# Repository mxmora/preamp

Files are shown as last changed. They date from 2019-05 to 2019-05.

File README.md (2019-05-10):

# preamp
Guitar buffer preamp

Added buffer input front end
Added more mounting holes

Version 1.1.4 only has the channel A clean section.
Version 1.1.4 has been built and tested and works with no error. Four minor errors were corrected and new boards were made.

Added Distortion Section
changed version to 1.2.0

This now has an A/B section A for clean and B for Lead Channel. 

Added LED for channel B indicator.

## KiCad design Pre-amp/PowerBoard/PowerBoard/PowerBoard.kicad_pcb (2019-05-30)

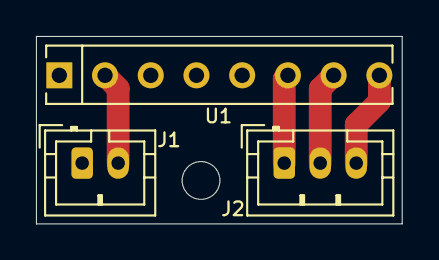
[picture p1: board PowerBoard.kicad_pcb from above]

Board: 2 copper layers, 20.3 x 10.4 mm, 4 parts (0 on the bottom side), 5 nets.

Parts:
H1: MountingHole; MountingHole_2.1mm
J1: Conn_01x02_Male; JST_PH_B2B-PH-K_1x02_P2.00mm_Vertical
J2: Conn_01x03_Male; JST_PH_B3B-PH-K_1x03_P2.00mm_Vertical
U1: DPAN02; SIP-8_19x3mm_P2.54mm

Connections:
+9V: J1.2, U1.2
+15V: J2.1, U1.6
-15V: J2.3, U1.8
GND: J1.1, U1.1
unnamed: J2.2, U1.7

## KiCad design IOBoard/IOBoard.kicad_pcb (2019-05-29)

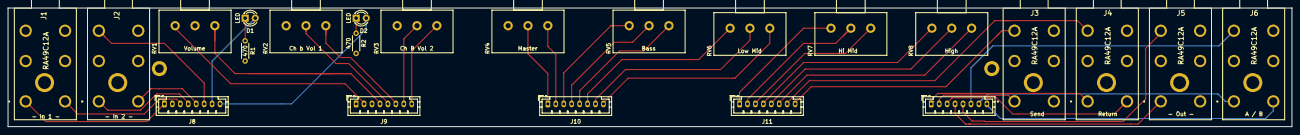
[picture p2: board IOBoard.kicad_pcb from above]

Board: 2 copper layers, 323.2 x 29.8 mm, 25 parts (0 on the bottom side), 40 nets.

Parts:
D1, D2: LED; LED_D3.0mm
H1, H2: MountingHole_Pad; MountingHole_2.2mm_M2_DIN965_Pad
J1, J2, J3, J4, J5, J6: RA49C12A; RA49C14B
J7, J8, J9, J10, J11: Conn_01x08_Male; JST_PH_B8B-PH-K_1x08_P2.00mm_Vertical
R1, R2: 470; R_Axial_DIN0204_L3.6mm_D1.6mm_P5.08mm_Horizontal
RV1: Volume; Potentiometer_Alps_RK163_Single_Horizontal
RV2: Ch b Vol 1; Potentiometer_Alps_RK163_Single_Horizontal
RV3: Ch B Vol 2; Potentiometer_Alps_RK163_Single_Horizontal
RV4: Master; Potentiometer_Alps_RK163_Single_Horizontal
RV5: Bass; Potentiometer_Alps_RK163_Single_Horizontal
RV6: Low Mid; Potentiometer_Alps_RK163_Single_Horizontal
RV7: Hi Mid; Potentiometer_Alps_RK163_Single_Horizontal
RV8: High; Potentiometer_Alps_RK163_Single_Horizontal

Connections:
GND: H1.1, H2.1, J1.5, J8.2, J9.3, R1.2, R2.2, RV1.2, RV2.3, RV3.3, RV4.3
unnamed: D1.1, R1.1
unnamed: D1.2, J8.7
unnamed: D2.1, R2.1
unnamed: D2.2, J8.8
unnamed: J1.1, J8.1
unnamed: J1.2, J8.3
unnamed: J2.1, J8.4
unnamed: J2.2, J8.5
unnamed: J2.5, J8.6
unnamed: J3.1, J7.2
unnamed: J4.1, J7.1
unnamed: J4.2, J7.3
unnamed: J5.1, J7.4
unnamed: J5.5, J7.5
unnamed: J6.1, J7.7
unnamed: J6.2, J7.8
unnamed: J6.5, J7.6
unnamed: J9.2, RV1.3
unnamed: J9.4, RV1.1
unnamed: J9.5, RV2.2
unnamed: J9.6, RV2.1
unnamed: J9.7, RV3.2
unnamed: J9.8, RV3.1
unnamed: J10.1, RV4.2
unnamed: J10.2, RV4.1
unnamed: J10.3, RV5.3
unnamed: J10.4, RV5.2
unnamed: J10.5, RV5.1
unnamed: J10.6, RV6.3
unnamed: J10.7, RV6.2
unnamed: J10.8, RV6.1
unnamed: J11.1, RV7.3
unnamed: J11.2, RV7.2
unnamed: J11.3, RV7.1
unnamed: J11.4, RV8.3
unnamed: J11.5, RV8.2
unnamed: J11.6, RV8.1
unnamed: J4.5, J11.7
unnamed: J3.5, J11.8

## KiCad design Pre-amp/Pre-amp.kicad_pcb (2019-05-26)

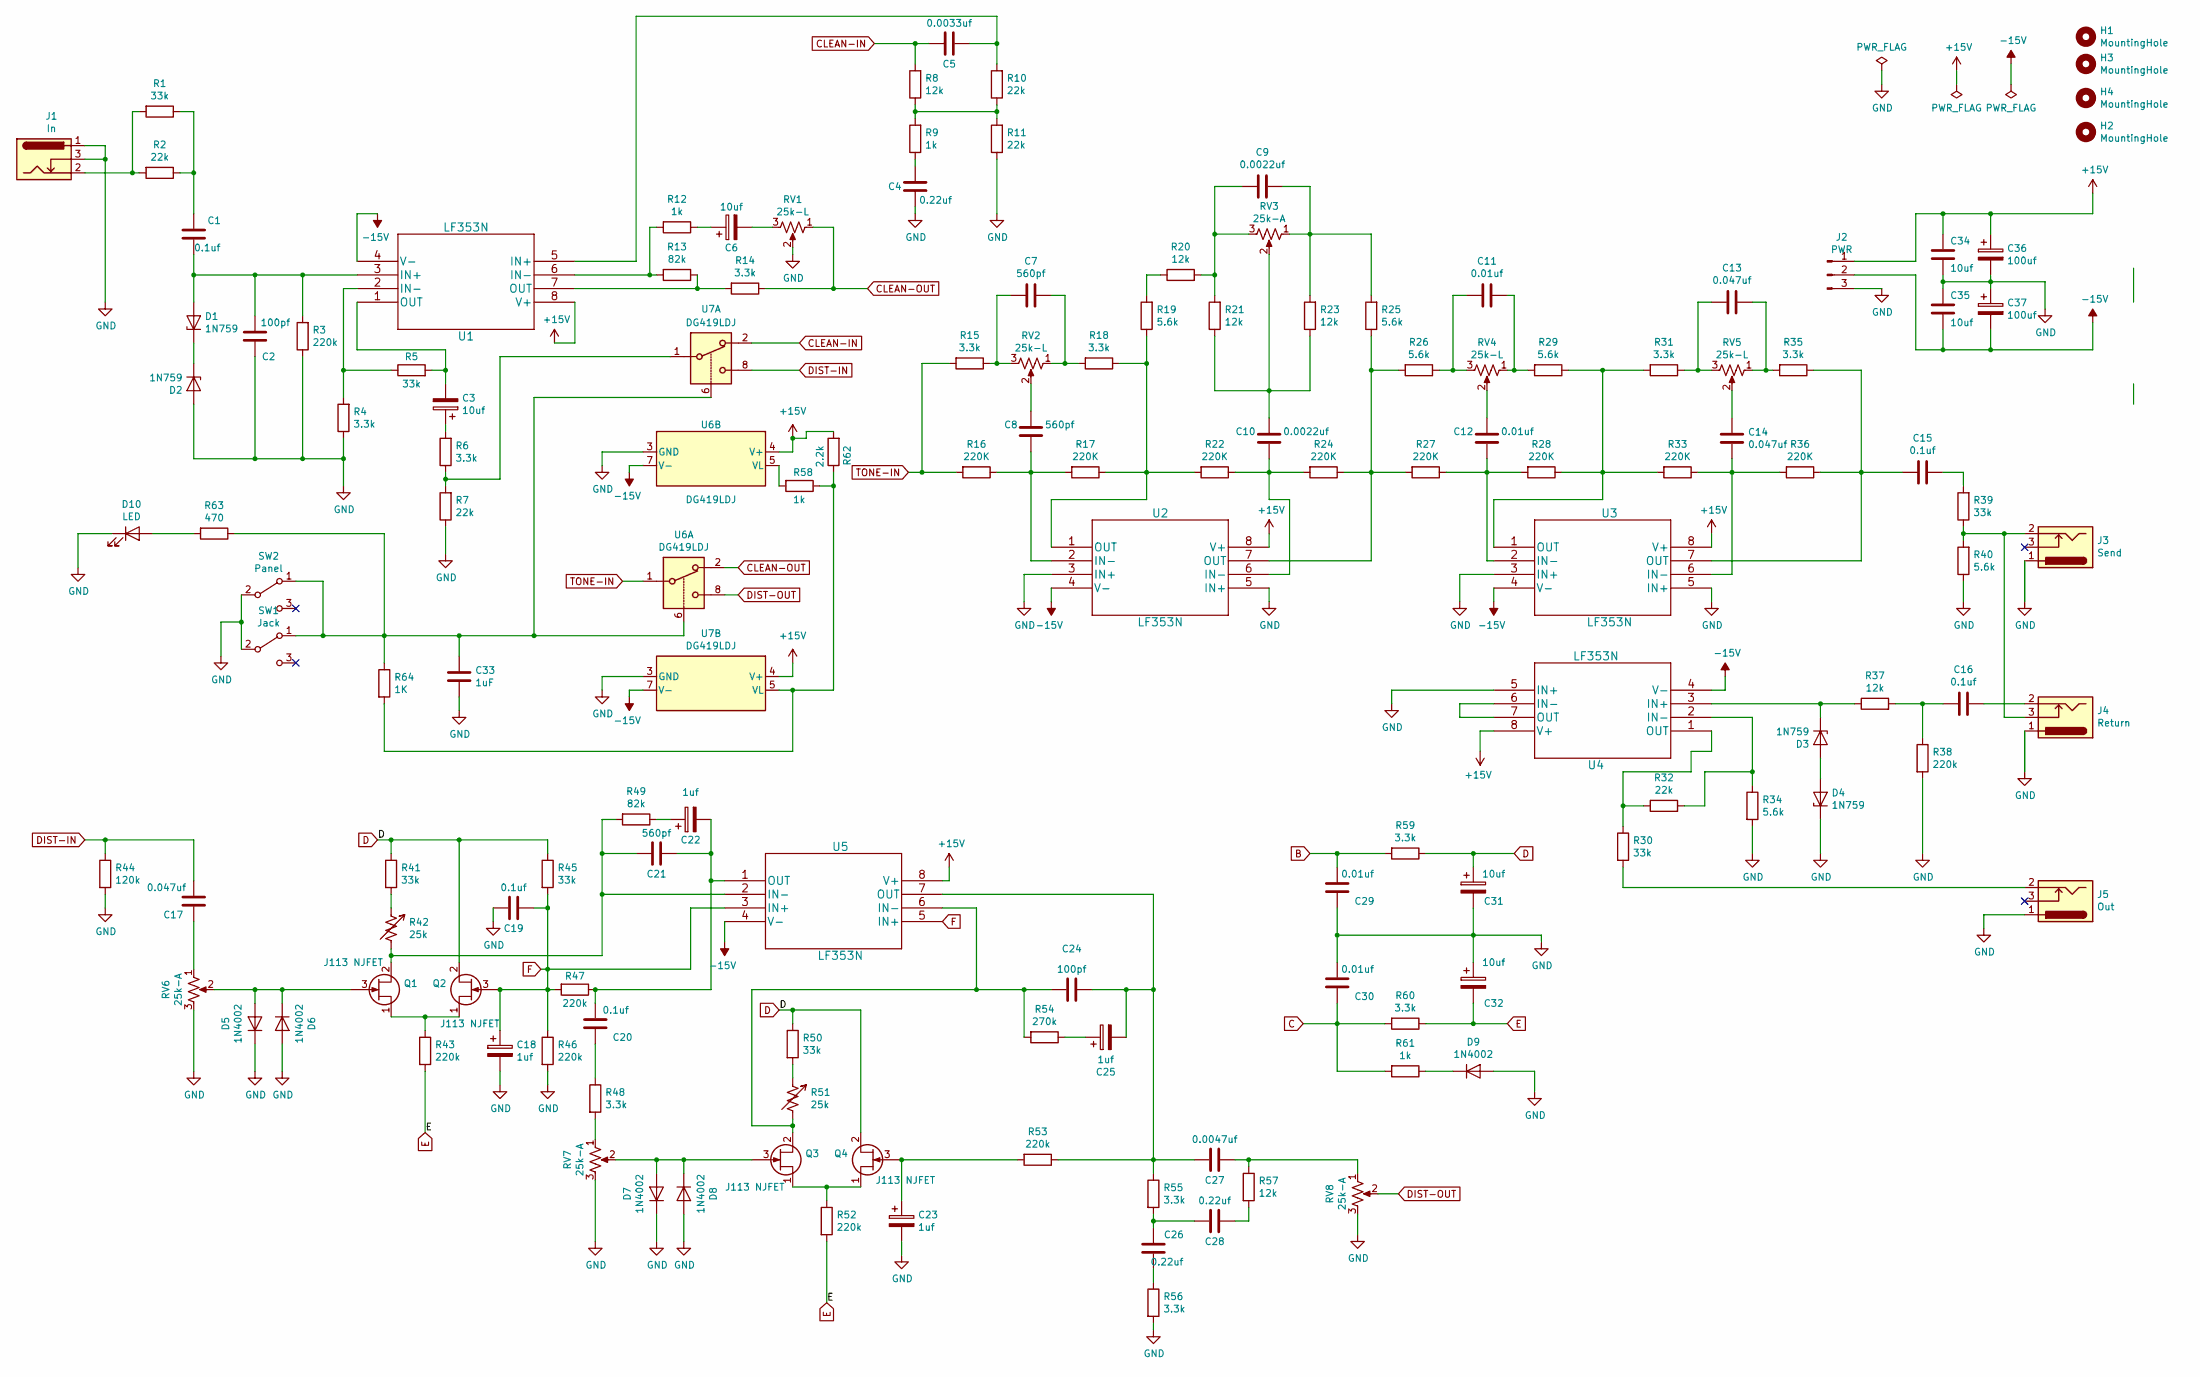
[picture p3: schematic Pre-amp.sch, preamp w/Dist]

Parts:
C1, C15, C16, C19, C20: 0.1uf; C_Disc_D3.8mm_W2.6mm_P2.50mm
C2, C24: 100pf; C_Disc_D3.8mm_W2.6mm_P2.50mm
C3, C6, C31, C32: 10uf; CP_Radial_D4.0mm_P1.50mm
C4, C26, C28: 0.22uf; C_Disc_D3.8mm_W2.6mm_P2.50mm
C5: 0.0033uf; C_Disc_D3.8mm_W2.6mm_P2.50mm
C7, C8, C21: 560pf; C_Disc_D3.8mm_W2.6mm_P2.50mm
C9, C10: 0.0022uf; C_Disc_D3.8mm_W2.6mm_P2.50mm
C11, C12, C29, C30: 0.01uf; C_Disc_D3.8mm_W2.6mm_P2.50mm
C13, C14, C17: 0.047uf; C_Disc_D3.8mm_W2.6mm_P2.50mm
C18, C22, C23, C25: 1uf; CP_Radial_D4.0mm_P1.50mm
C27: 0.0047uf; C_Disc_D3.8mm_W2.6mm_P2.50mm
C33: 1uF; C_Rect_L7.0mm_W2.0mm_P5.00mm
C34, C35: 10uf; C_Disc_D6.0mm_W2.5mm_P5.00mm
C36, C37: 100uf; CP_Radial_D8.0mm_P5.00mm
D1, D2, D3, D4: 1N759; D_DO-35_SOD27_P7.62mm_Horizontal
D5, D6, D7, D8, D9: 1N4002; D_DO-41_SOD81_P7.62mm_Horizontal
D10: LED; PinHeader_2x01_P2.00mm_Vertical
H1, H2, H3, H4: MountingHole; MountingHole_2.2mm_M2_DIN965_Pad
J1: In; PinHeader_1x03_P2.00mm_Vertical
J2: PWR; PinHeader_1x03_P2.00mm_Vertical
J3: Send; PinHeader_1x03_P2.00mm_Vertical
J4: Return; PinHeader_1x03_P2.00mm_Vertical
J5: Out; PinHeader_1x03_P2.00mm_Vertical
Q1, Q2, Q3, Q4: J113 NJFET; TO-92
R1, R5, R30, R39, R41, R45, R50: 33k; R_Axial_DIN0204_L3.6mm_D1.6mm_P5.08mm_Horizontal
R2, R7, R10, R11, R32: 22k; R_Axial_DIN0204_L3.6mm_D1.6mm_P5.08mm_Horizontal
R3, R38, R43, R46, R47, R52, R53: 220k; R_Axial_DIN0204_L3.6mm_D1.6mm_P5.08mm_Horizontal
R4, R6, R14, R15, R18, R31, R35, R48, R55, R56, R59, R60: 3.3k; R_Axial_DIN0204_L3.6mm_D1.6mm_P5.08mm_Horizontal
R8, R20, R21, R23, R37, R57: 12k; R_Axial_DIN0204_L3.6mm_D1.6mm_P5.08mm_Horizontal
R9, R12, R58, R61: 1k; R_Axial_DIN0204_L3.6mm_D1.6mm_P5.08mm_Horizontal
R13, R49: 82k; R_Axial_DIN0204_L3.6mm_D1.6mm_P5.08mm_Horizontal
R16, R17, R22, R24, R27, R28, R33, R36: 220K; R_Axial_DIN0204_L3.6mm_D1.6mm_P5.08mm_Horizontal
R19, R25, R26, R29, R34, R40: 5.6k; R_Axial_DIN0204_L3.6mm_D1.6mm_P5.08mm_Horizontal
R42, R51: 25k; Potentiometer_Bourns_3386F_Vertical
R44: 120k; R_Axial_DIN0204_L3.6mm_D1.6mm_P5.08mm_Horizontal
R54: 270k; R_Axial_DIN0204_L3.6mm_D1.6mm_P5.08mm_Horizontal
R62: 2.2k; R_Axial_DIN0204_L3.6mm_D1.6mm_P5.08mm_Horizontal
R63: 470; R_Axial_DIN0204_L3.6mm_D1.6mm_P5.08mm_Horizontal
R64: 1K; R_Axial_DIN0204_L3.6mm_D1.6mm_P5.08mm_Horizontal
RV1, RV2, RV4, RV5: 25k-L; Potentiometer_Alps_RK163_Single_Vertical
RV3, RV6, RV7, RV8: 25k-A; Potentiometer_Alps_RK163_Single_Vertical
SW1: Jack; Pin_Header_Straight_1x03_Pitch2.00mm
SW2: Panel; Pin_Header_Straight_1x03_Pitch2.00mm
U1, U2, U3, U4, U5: LF353N; DIP-8_W7.62mm_LongPads
U6, U7: DG419LDJ; DIP-8_W7.62mm_LongPads

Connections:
+15V: C34.1, C36.1, J2.1, R62.2, U1.8 (V+), U2.8 (V+), U3.8 (V+), U4.8 (V+), U5.8 (V+), U6.4 (V+), U7.4 (V+)
-15V: C35.2, C37.2, J2.2, U1.4 (V-), U2.4 (V-), U3.4 (V-), U4.4 (V-), U5.4 (V-), U6.7 (V-), U7.7 (V-)
B: C29.1, R59.2
C: C30.2, R60.2, R61.2
CLEAN-IN: C5.1, R8.2, U7.2
CLEAN-OUT: R14.1, RV1.1, U6.2
D: C31.1, Q2.2 (D), Q4.2 (D), R41.1, R45.1, R50.1, R59.1
DIST-IN: C17.1, R44.1, U7.8
DIST-OUT: RV8.2, U6.8
E: C32.2, R43.2, R52.2, R60.1
F: C18.1, C19.1, Q2.3 (G), R45.2, R46.1, R47.2, U5.3 (IN+), U5.5 (IN+)
GND: C2.1, C4.2, C18.2, C19.2, C23.2, C29.2, C30.1, C31.2, C32.1, C33.2, C34.2, C35.1, C36.2, C37.1, D2.2 (A), D4.1 (K), D5.1 (K), D6.2 (A), D7.1 (K), D8.2 (A), D9.2 (A), D10.1 (K), J1.1, J1.3, J2.3, J3.1, J4.1, J5.1, R3.1, R4.1, R7.1, R11.1, R34.2, R38.2, R40.1, R44.2, R46.2, R56.2, RV1.2, RV6.3, RV7.3, RV8.3, SW1.2 (B), SW2.2 (B), U2.3 (IN+), U2.5 (IN+), U3.3 (IN+), U3.5 (IN+), U4.5 (IN+), U6.3 (GND), U7.3 (GND)
unnamed: C1.1, C2.2, D1.2 (A), R3.2, U1.3 (IN+)
unnamed: C1.2, R1.1, R2.1
unnamed: C3.1, R6.2
unnamed: C3.2, R5.2, U1.1 (OUT)
unnamed: C4.1, R9.1
unnamed: C5.2, R10.2, U1.5 (IN+)
unnamed: C6.1, R12.1
unnamed: C6.2, RV1.3
unnamed: C7.1, R18.2, RV2.1
unnamed: C7.2, R15.1, RV2.3
unnamed: C8.1, RV2.2
unnamed: C8.2, R16.1, R17.2, U2.2 (IN-)
unnamed: C9.1, R23.2, R25.2, RV3.1
unnamed: C9.2, R20.2, R21.2, RV3.3
unnamed: C10.1, R21.1, R23.1, RV3.2
unnamed: C10.2, R22.1, R24.2, U2.6 (IN-)
unnamed: C11.1, R29.2, RV4.1
unnamed: C11.2, R26.1, RV4.3
unnamed: C12.1, RV4.2
unnamed: C12.2, R27.1, R28.2, U3.2 (IN-)
unnamed: C13.1, R35.2, RV5.1
unnamed: C13.2, R31.1, RV5.3
unnamed: C14.1, RV5.2
unnamed: C14.2, R33.1, R36.2, U3.6 (IN-)
unnamed: C15.1, R39.2
unnamed: C15.2, R35.1, R36.1, U3.7 (OUT)
unnamed: C16.1, J4.2
unnamed: C16.2, R37.2, R38.1
unnamed: C17.2, RV6.1
unnamed: C20.1, C21.1, C22.2, R47.1, U5.1 (OUT)
unnamed: C20.2, R48.1
unnamed: C21.2, Q1.2 (D), R42.2, R49.2, U5.2 (IN-)
unnamed: C22.1, R49.1
unnamed: C23.1, Q4.3 (G), R53.2
unnamed: C24.1, C25.2, C27.1, R53.1, R55.1, U5.7 (OUT)
unnamed: C24.2, Q3.2 (D), R51.2, R54.2, U5.6 (IN-)
unnamed: C25.1, R54.1
unnamed: C26.1, R56.1
unnamed: C26.2, C28.1, R55.2
unnamed: C27.2, R57.1, RV8.1
unnamed: C28.2, R57.2
unnamed: C33.1, R63.1, R64.1, SW1.1 (A), SW2.1 (A), U6.6, U7.6
unnamed: D1.1 (K), D2.1 (K)
unnamed: D3.1 (K), R37.1, U4.3 (IN+)
unnamed: D3.2 (A), D4.2 (A)
unnamed: D5.2 (A), D6.1 (K), Q1.3 (G), RV6.2
unnamed: D7.2 (A), D8.1 (K), Q3.3 (G), RV7.2
unnamed: D9.1 (K), R61.1
unnamed: D10.2 (A), R63.2
unnamed: J1.2, R1.2, R2.2
unnamed: J3.2, J4.3, R39.1, R40.2
unnamed: J5.2, R30.2
unnamed: Q1.1 (S), Q2.1 (S), R43.1
unnamed: Q3.1 (S), Q4.1 (S), R52.1
unnamed: R4.2, R5.1, U1.2 (IN-)
unnamed: R6.1, R7.2, U7.1
unnamed: R8.1, R9.2, R10.1, R11.2
unnamed: R12.2, R13.2, U1.6 (IN-)
unnamed: R13.1, R14.2, U1.7 (OUT)
unnamed: R17.1, R18.1, R19.1, R22.2, U2.1 (OUT)
unnamed: R19.2, R20.1
unnamed: R24.1, R25.1, R26.2, R27.2, U2.7 (OUT)
unnamed: R28.1, R29.1, R31.2, R33.2, U3.1 (OUT)
unnamed: R30.1, R32.1, U4.1 (OUT)
unnamed: R32.2, R34.1, U4.2 (IN-)
unnamed: R41.2, R42.1
unnamed: R48.2, RV7.1
unnamed: R50.2, R51.1
unnamed: R58.1, R62.1, R64.2, U7.5 (VL)
unnamed: R58.2, U6.5 (VL)
unnamed: U4.6 (IN-), U4.7 (OUT)
TONE-IN: R15.2, R16.2, U6.1

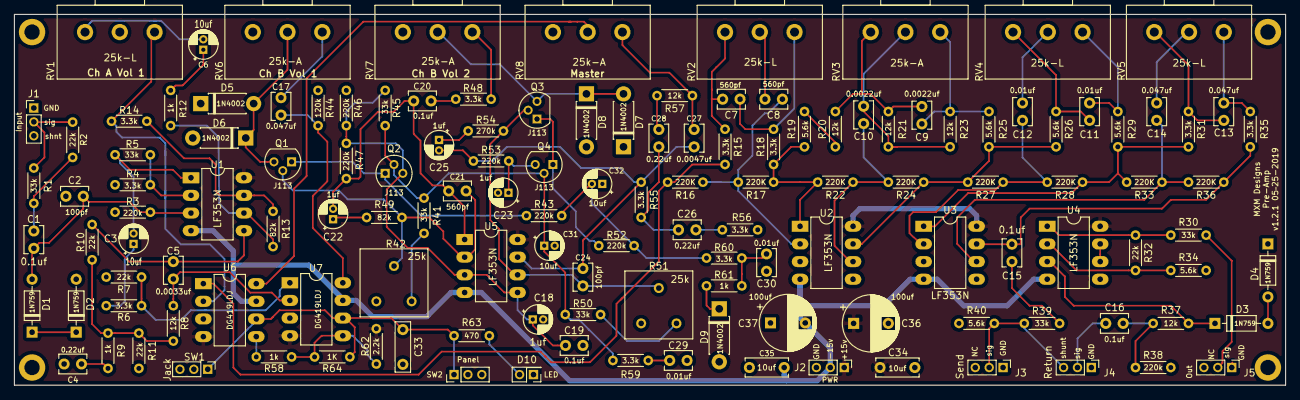
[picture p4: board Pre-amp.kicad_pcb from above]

Board: 2 copper layers, 182.9 x 53.3 mm, 141 parts (0 on the bottom side), 84 nets.

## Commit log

2019-04-01 Add buffer input to pre-amp
    [Pre-amp-B.Adhes.gbr, Pre-amp-B.CrtYd.gbr, Pre-amp-B.Cu.gbr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]
2019-04-02 update version
    [Pre-amp.kicad_pcb, Pre-amp.sch]
2019-04-02 update layout move vaules to silkscreen layer. Change some routes to give more room around pads.
    [Pre-amp-B_Adhes.gbr, Pre-amp-B_CrtYd.gbr, Pre-amp-B_Cu.gbr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]
2019-04-02 update to pc mount pots
    [Pre-amp-B_Adhes.gbr, Pre-amp-B_CrtYd.gbr, Pre-amp-B_Cu.gbr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]
2019-04-19 add switching
    [Pre-amp.sch]
2019-04-28 Fix errors found in build. Change version to 1.2.0
    [Pre-amp.sch]
2019-04-30 update schematic symbols
    [Pre-amp.kicad_pcb, Pre-amp.sch]
2019-05-01 update schematic for distortion section
    [Pre-amp.kicad_pcb, Pre-amp.sch]
2019-05-01 place all components
    [Pre-amp.kicad_pcb, Pre-amp.sch]
2019-05-01 get all parts on the board
    [Pre-amp.kicad_pcb, Pre-amp.sch]
2019-05-06 update the schematic and PCB for lead section.
    [Pre-amp.kicad_pcb, Pre-amp.sch]
2019-05-07 connect all traces
    [Pre-amp.kicad_pcb]
2019-05-07 add bom
2019-05-07 clean up PCB
    [Pre-amp.kicad_pcb]
2019-05-09 fx botch git commits
    [Pre-amp.kicad_pcb, Pre-amp.sch]
2019-05-09 spread out components better.
    [Pre-amp.kicad_pcb, Pre-amp.sch]
2019-05-10 update PCB
    [Pre-amp.kicad_pcb]
2019-05-12 tweak PCB layout
    [Pre-amp.kicad_pcb, Pre-amp.sch]
2019-05-12 add power caps
    [Pre-amp.kicad_pcb, Pre-amp.sch]
2019-05-14 Rearrange the board for taller things to be away from the edges.
    [Pre-amp.kicad_pcb]
2019-05-15 Add IOBoard
    [IOBoard.kicad_pcb, IOBoard.sch, Pre-amp.kicad_pcb]
2019-05-15 add jacks
    [IOBoard.kicad_pcb, IOBoard.sch]
2019-05-16 split connectors and reflow
    [IOBoard.kicad_pcb, IOBoard.sch]
2019-05-26 fix 1uf caps to CP
    [Pre-amp.kicad_pcb, Pre-amp.sch]
2019-05-29 move to the same size connectors
    [IOBoard.kicad_pcb, IOBoard.sch]
2019-05-30 add power convertor board
    [PowerBoard.kicad_pcb, PowerBoard.sch]
